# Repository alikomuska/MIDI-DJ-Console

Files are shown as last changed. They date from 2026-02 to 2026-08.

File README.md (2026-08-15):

# 🎛️ DIY MIDI DJ Console

<p align="center">
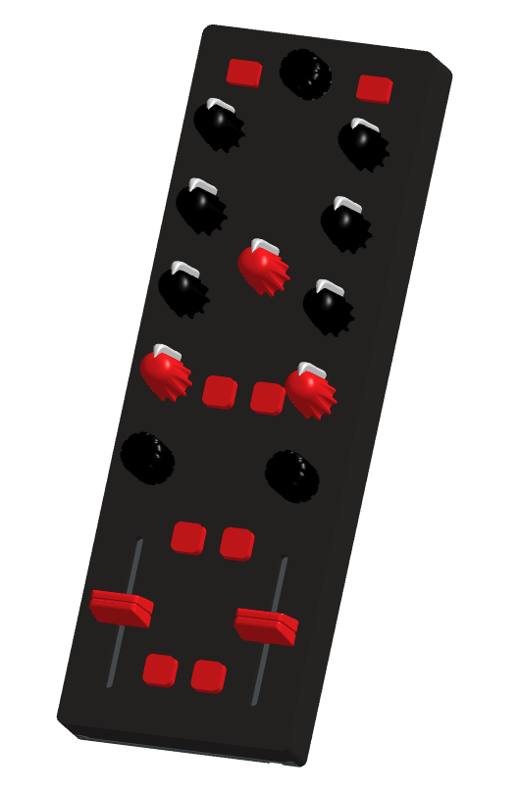
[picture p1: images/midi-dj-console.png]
DIY MIDI DJ Console
  
</p>

## 🎚️ What is this?

A custom-built **MIDI DJ console** designed and built from scratch. The console provides **MIDI control only** and does not include a built-in sound card.

## 🎧 2 → 4 Deck Expansion
It is designed primarily as an **extension controller**, making it ideal for expanding a standard **2-deck DJ setup into a 4-deck setup** without replacing the existing controller.

## 🔴⚫ The Console

The console features:

* 🎚️ Rotary controls for EQ, filter, gain, and other parameters
* 🎚️ Faders
* 🔘 Buttons
* 🎛️ Rotary controls

The layout is focused on providing additional hands-on controls for DJs who want to expand their setup while keeping their existing 2-deck controller.

Because the console is MIDI-only, it can be mapped to DJ software to suit the user's preferred workflow and configuration.

## 🛠️ Components Needed

### Potentiometers & Controls

| Component | Quantity | Description | Link |
|---|---|---|---|
| **RV09 Potentiometers** | 9 | Rotary potentiometers for EQ, gain, filter, and other parameters | [AliExpress](https://www.aliexpress.com/item/1005006950939111.html?spm=a2g0o.order_list.order_list_main.5.75bc1802wQvTmo) |
| **60mm Sliding Potentiometers** | 2 | Linear faders for volume or channel control | [AliExpress](https://www.aliexpress.com/item/1005009375810589.html?spm=a2g0o.order_list.order_list_main.97.75bc1802wQvTmo) |
| **Rotary Encoder Switch EC11** | 1 | Rotary encoder with push-button for navigation or parameter selection | [AliExpress](https://www.aliexpress.com/item/1005006076665259.html?spm=a2g0o.order_list.order_list_main.62.75bc1802wQvTmo) |
| **Rotary Encoders** | 2 | Standard rotary encoders for loop | |
| **Push Buttons (Tactile Switches)** | 8 | Momentary push buttons for cue, play, shift, and other performance functions | |

### Microcontroller & Signal Processing

| Component | Quantity | Description | Link |
|---|---|---|---|
| **Raspberry Pi Pico RP2040** | 1 | Microcontroller board that handles MIDI communication and input processing | |
| **Multiplexer CD74HC4067** | 1 | 16-channel analog multiplexer for expanding the number of analog inputs on the Pico | [AliExpress](https://www.aliexpress.com/item/1005009887874792.html?spm=a2g0o.order_list.order_list_main.72.75bc1802wQvTmo) |

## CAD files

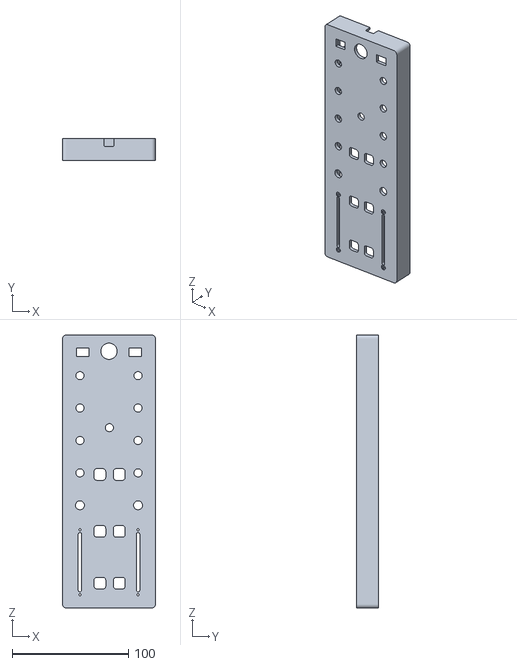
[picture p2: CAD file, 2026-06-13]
stl/Console - Top part.stl
80.0 x 19.0 x 235.0

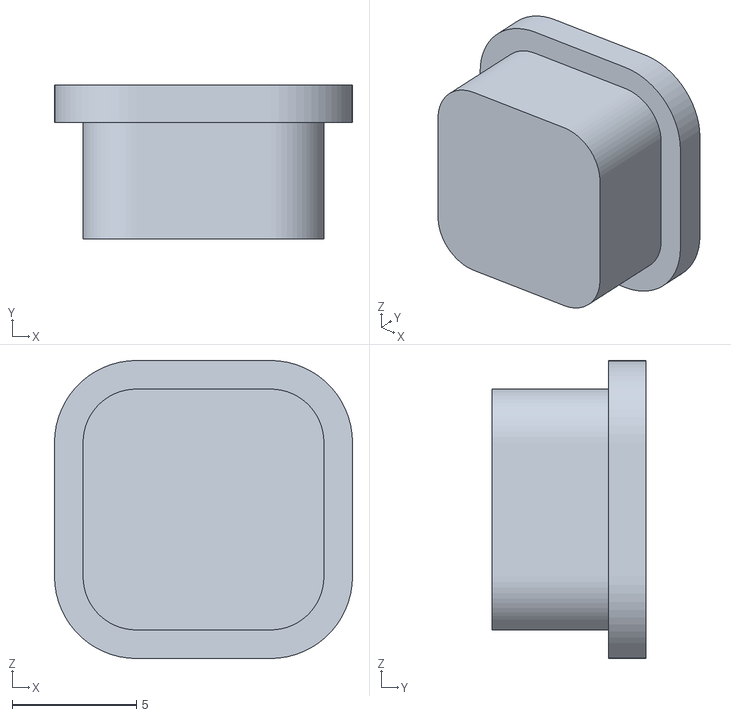
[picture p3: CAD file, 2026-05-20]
stl/Button_small.stl
12.0 x 6.20 x 12.0

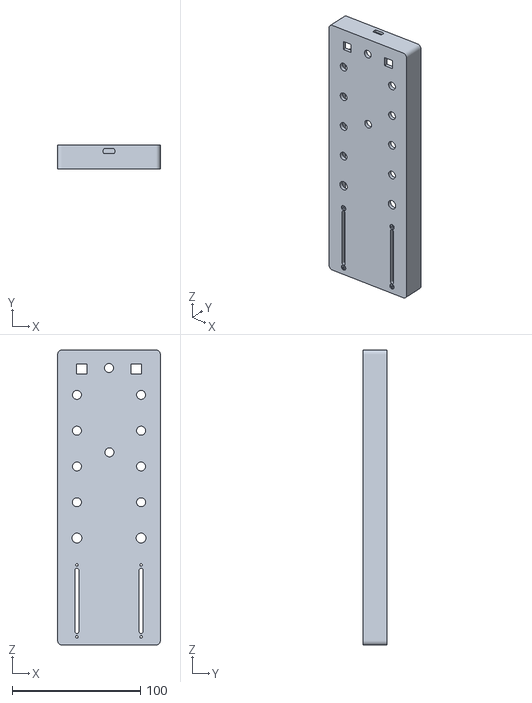
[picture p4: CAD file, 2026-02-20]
stl/top_part.stl
80.0 x 19.0 x 230.0

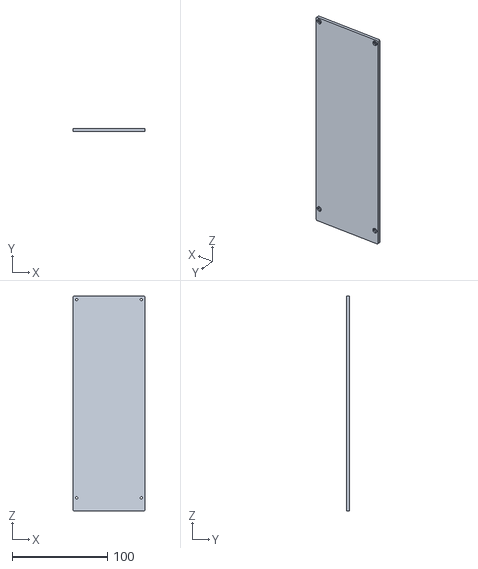
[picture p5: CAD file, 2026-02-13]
stl/Bottom part.stl
75.4 x 3.00 x 225.4

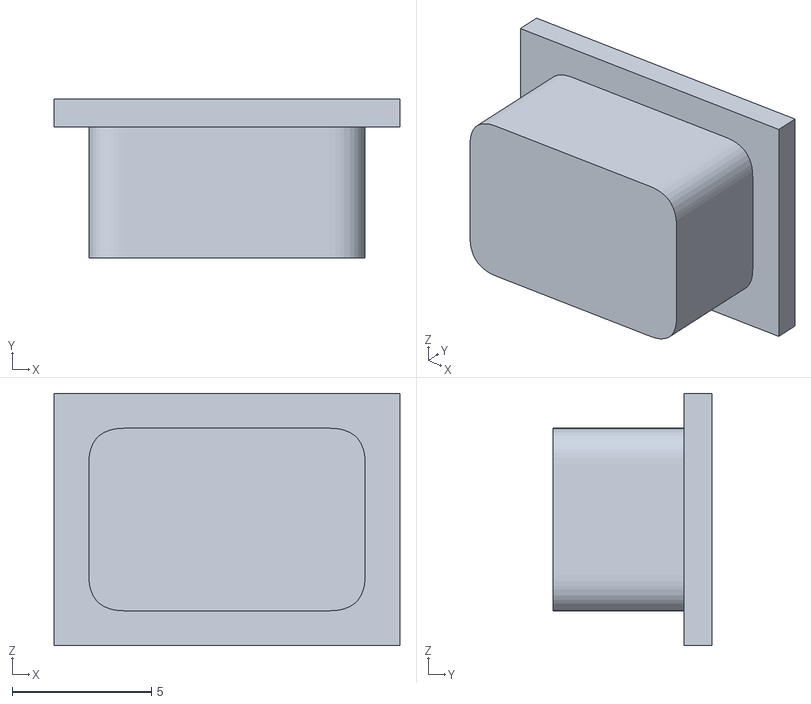
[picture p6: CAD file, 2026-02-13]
stl/Button.stl
12.4 x 5.70 x 9.06

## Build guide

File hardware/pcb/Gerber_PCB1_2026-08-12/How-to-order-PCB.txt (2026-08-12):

How to Order PCB

Please refer to:
https://prodocs.easyeda.com/en/pcb/order-order-pcb/index.html

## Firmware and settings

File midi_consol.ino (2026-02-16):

#include "MIDIUSB.h"
#define NUM_POTS 9
#define NUM_ROTS 2
#define NUM_BUTS 2

const int CHANNEL = 0;
const int NOISE_THRESHOLD = 2;
//int ccNumbers[] = {0, 1, 2, 3, 4, 5, 6, 7}; //not needed maybe later


//#########  POTENSIOMETERS ############
int potPin[] = {A0, A1, A2, A3, A6, A7, A8, A10, A9};  // Potentiometer pins
int lastValues[] = {-1, -1, -1, -1, -1, -1, -1, -1, -1};  // To prevent sending redundant MIDI messages


//#########  ROTARY ############
int rotPin[] = {7, 5, 14, 16};
int rotaryLastStates[NUM_ROTS];


//########## BUTTONS ############
int butPin[] = {3,15};
bool lastButtonState[NUM_BUTS] = {HIGH, HIGH};


//##########   MIDI  ############
int loopValue = 0;
bool loopOn[NUM_BUTS] = {false, false};



// Send a MIDI Control Change message
void controlChange(byte channel, byte control, byte value) {
  midiEventPacket_t event = {0x0B, 0xB0 | channel, control, value};
  MidiUSB.sendMIDI(event);
}

void _initPot() {
  // Could put some more thought into it, but works fine
  int midiValue, potValue;
  double start = millis();
  for(int i=0; i<NUM_POTS; i++){
    pinMode(potPin[i], INPUT);
  }
  while (true) {
    midiEventPacket_t rx = MidiUSB.read(); 

    // Check if we got any MIDI packet from the computer
    if (rx.header != 0) { //use Monitor State midi out from traktor
      break; // exit the loop
    }

    delay(5); // small pause so we don't hammer USB bus
    if (millis() - start > 4000) {
      break;
    }
  }

  for(int i=0; i<NUM_POTS; i++){
    potValue = constrain(analogRead(potPin[i]), 0, 1023);
    midiValue = map(potValue, 0, 1023, 0, 127); // Convert to MIDI range (0–127)
    controlChange(CHANNEL, i, midiValue);  // Channel 0, CC #7 = volume (standard)
    lastValues[i] = midiValue;
  }
  MidiUSB.flush(); 
}

void _initRot(){
  for(int i=0; i<(NUM_ROTS*2); i++){
     pinMode(rotPin[i], INPUT_PULLUP);
  }
  for(int i=0; i<NUM_ROTS; i++){
    rotaryLastStates[i] = digitalRead(rotPin[i*2]);
  }
  
}

void _iniBut(){
  for(int i=0; i<NUM_BUTS; i++){
    pinMode(butPin[i], INPUT_PULLUP);
  }
}

void initConsole(){
  _initPot();
  _initRot();
  _iniBut();
  }

//Potentiometer update
void update_pot(){
  int midiValue, potValue;
  for(int i=0; i<NUM_POTS; i++){
    potValue = analogRead(potPin[i]);
    midiValue = map(potValue, 0, 1023, 0, 127);
    if(abs(midiValue - lastValues[i]) > NOISE_THRESHOLD){ //if you add capasitors so the analogReads are noice resistant you can check if the value changed
      controlChange(CHANNEL, i, midiValue);
      lastValues[i] = midiValue;
      Serial.println(i);
      Serial.println(potValue);
    }
  }
}

  //0 -> 1/32
  //7 -> 1/16
  //20 -> 1/8
  //32 -> 1/4
  //45 -> 1/2
  //58 -> 1
  //70 -> 2
  //83 -> 4
  //96 -> 8
  //108 -> 16
  //121 -> 32
void update_rot(){
  int rotState;
  int pinA, pinB;
  for (int i = 0; i < NUM_ROTS; i++) {
    pinA = rotPin[2*i];
    pinB = rotPin[2*i+1];
    rotState = digitalRead(pinA);
    if(rotState != rotaryLastStates[i]){
      if (rotState == HIGH) {
        if(digitalRead(pinB) == rotState) {
          //loopValue = min(loopValue + 13, 127);
          controlChange(CHANNEL, NUM_POTS+i*2, 127);
          Serial.print(i);
          Serial.println(" LOW");
        } else {
          //loopValue = max(loopValue - 13, 0);
          controlChange(CHANNEL, NUM_POTS+i*2+1, 127);
          Serial.print(i);
          Serial.println(" HIGH");
        }
      }
      rotaryLastStates[i] = rotState;
    }
  }
}


//Buttons
void update_buts(){
  bool currentState;

  for(int i=0; i<NUM_BUTS; i++){
    // button pressed (HIGH → LOW)
    currentState = digitalRead(butPin[i]);
    if (currentState == LOW && lastButtonState[i] == HIGH) {
      controlChange(CHANNEL, NUM_POTS + NUM_ROTS*2 + i, 127);
      Serial.print(NUM_POTS + NUM_ROTS*2 + i);
      Serial.println(" LOOP");  
    }
    lastButtonState[i] = currentState;
    //loopOn[i]= !loopOn[i];
 

    // button released (LOW → HIGH)
    if (currentState == HIGH && lastButtonState[i] == LOW) {
      controlChange(CHANNEL, NUM_POTS + NUM_ROTS*2 + i*2, 127);
      Serial.println("Realise");
      lastButtonState[i] = currentState;
    }
  }  
}


void setup() {
  Serial.begin(115200);
  initConsole();
}



void loop() {
  //Potentiometers
  update_pot();
  
  //Rotary Encoders
  update_rot();

  //Buttons
  update_buts();

  MidiUSB.flush();
  delay(1);
}

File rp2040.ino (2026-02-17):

#include <Adafruit_TinyUSB.h>

Adafruit_USBD_MIDI usb_midi;

// Send Note On
void midiNoteOn(uint8_t channel, uint8_t note, uint8_t velocity) {
  usb_midi.write((uint8_t)(0x90 | ((channel - 1) & 0x0F)));
  usb_midi.write(note);
  usb_midi.write(velocity);
}

// Send Note Off
void midiNoteOff(uint8_t channel, uint8_t note, uint8_t velocity) {
  usb_midi.write((uint8_t)(0x80 | ((channel - 1) & 0x0F)));
  usb_midi.write(note);
  usb_midi.write(velocity);
}

void setup() {
  usb_midi.begin();
}

void loop() {
  midiNoteOn(1, 60, 100);  // Channel 1, Middle C
  delay(100);

  midiNoteOff(1, 60, 0);
  delay(900); // total 1 second cycle
}
